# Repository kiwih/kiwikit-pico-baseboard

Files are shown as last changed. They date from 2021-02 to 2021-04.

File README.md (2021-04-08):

# Kiwikit Pico Baseboard

This board provides an easy-to-solder all-throughole 10cm x 10cm 2-layer board which is used in conjunction with a Raspberry Pi Pico for basic, fun experimentation!

render

Features include:
* Three general purpose buttons and a reset button,
* Two general purpose LEDs and a power LED,
* An I2C SSD1306 Screen,
* An I2C AT24 EEPROM
* An LDR for Analog experimentation,
* And a bunch more expansion ports, two of which are arranged to work with cheap SD card and accelerometer modules!

## Usage

The latest schematic in PDF format, and the latest version of the gerbers for manufacture, are located directly 
in the root folder of this repository.

Alternatively, if you want to change any settings / etc, you can download this repository and open it with Kicad.
If so, you'll use this project in tandem with my `kiwih_kicad` Kicad repository: https://github.com/kiwih/kiwih_kicad

## Further documentation

I wrote a blog post to go with this! You can find it [here](https://01001000.xyz/2021-02-13-Raspberry-Pi-Pico-dev-board-Kiwikit/).

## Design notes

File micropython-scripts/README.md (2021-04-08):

## micropython-scripts

In this directory are a number of small micropython scripts you can use to get started with experimenting on the kiwikit-pico-baseboard.

Copy over the at24.py and the ssd1306.py libraries and then you can launch kiwikit.py.

If you're unsure of what to do I recommend perusing the [resources](https://www.raspberrypi.org/documentation/rp2040/getting-started/#getting-started-with-micropython).

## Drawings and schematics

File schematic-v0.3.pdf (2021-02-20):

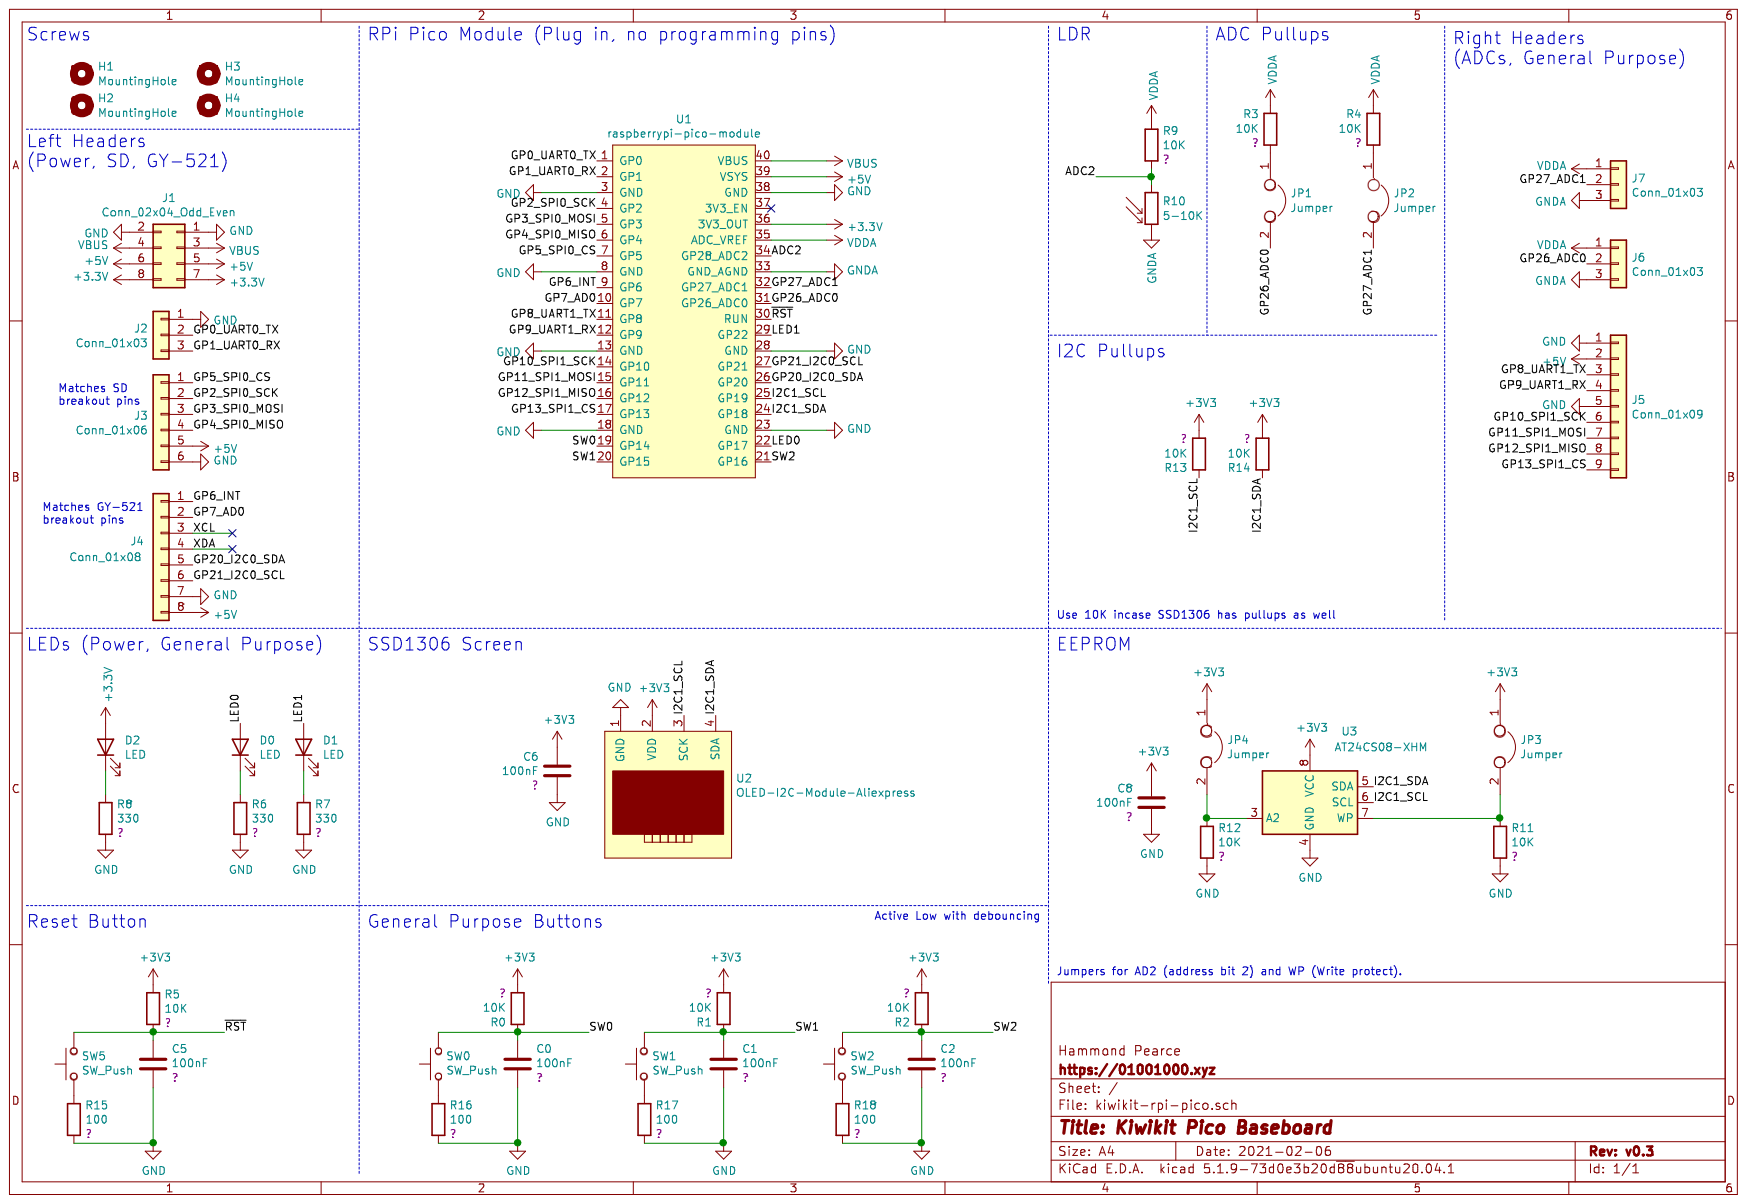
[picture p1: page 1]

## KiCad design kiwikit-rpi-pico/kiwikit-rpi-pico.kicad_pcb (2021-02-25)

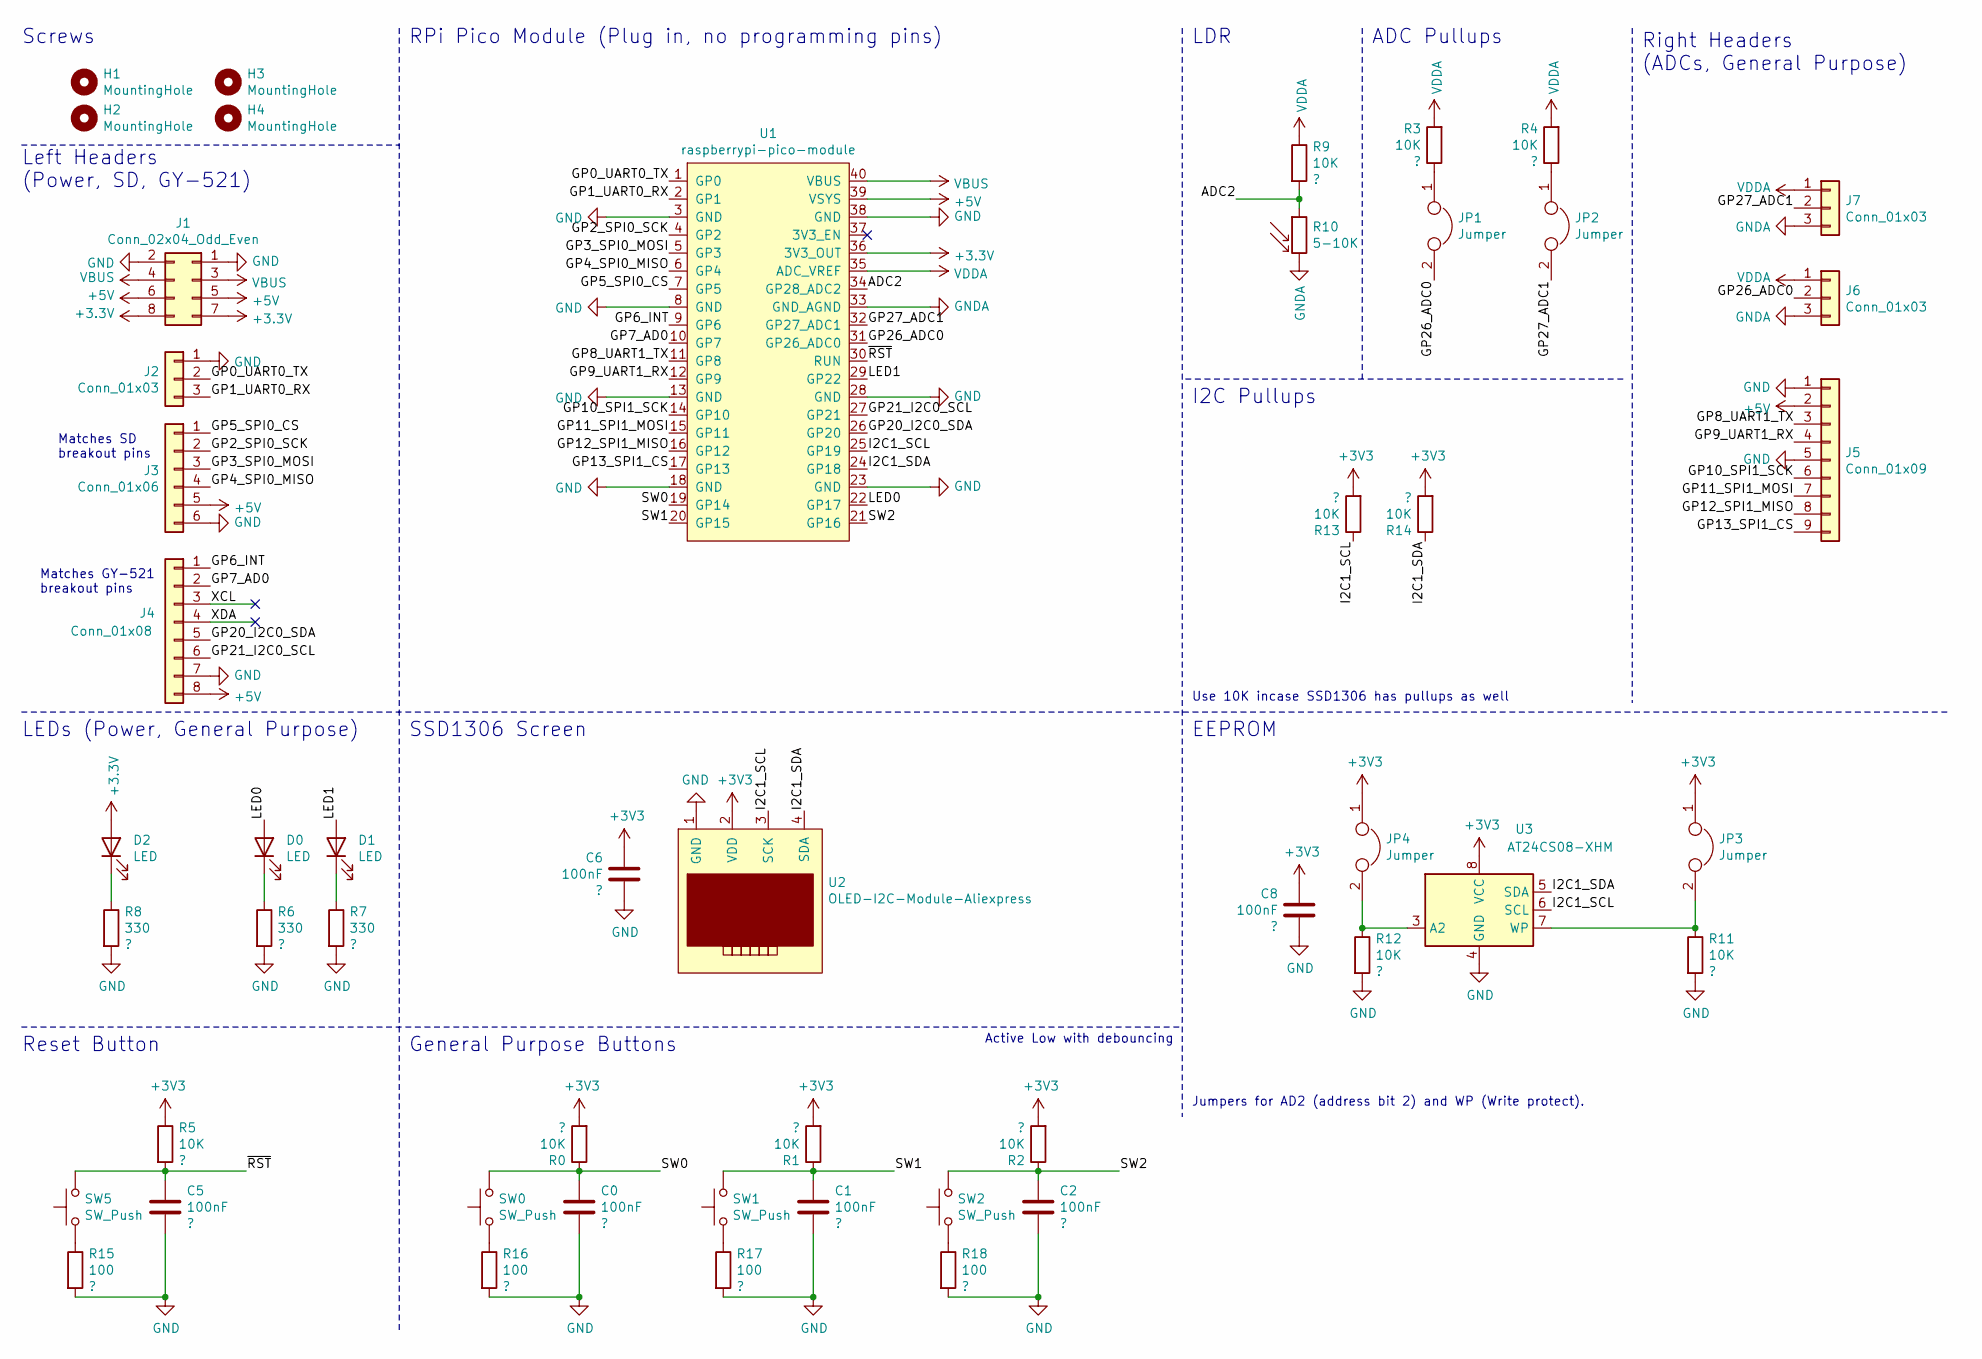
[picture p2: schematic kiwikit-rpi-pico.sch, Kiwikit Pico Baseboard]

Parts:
C0, C1, C2, C5, C6, C8: 100nF; C_Disc_D4.3mm_W1.9mm_P5.00mm
D0, D1, D2: LED; LED_D4.0mm
H1, H2, H3, H4: MountingHole; MountingHole_2.2mm_M2
J1: Conn_02x04_Odd_Even; PinHeader_2x04_P2.54mm_Vertical
J2, J6, J7: Conn_01x03; PinHeader_1x03_P2.54mm_Vertical
J3: Conn_01x06; PinSocket_1x06_P2.54mm_Vertical
J4: Conn_01x08; PinSocket_1x08_P2.54mm_Vertical
J5: Conn_01x09; PinHeader_1x09_P2.54mm_Vertical
JP1, JP2, JP3, JP4: Jumper; PinHeader_1x02_P2.54mm_Vertical
R0, R1, R2, R3, R4, R5, R9, R11, R12, R13, R14: 10K; R_Axial_DIN0207_L6.3mm_D2.5mm_P10.16mm_Horizontal
R6, R7, R8: 330; R_Axial_DIN0207_L6.3mm_D2.5mm_P10.16mm_Horizontal
R10: 5-10K; R_LDR_5.0x4.1mm_P3mm_Vertical
R15, R16, R17, R18: 100; R_Axial_DIN0207_L6.3mm_D2.5mm_P10.16mm_Horizontal
SW0, SW1, SW2: SW_Push; SW_PUSH_6mm_H9.5mm
SW5: SW_Push; SW_PUSH_6mm_H4.3mm
U1: raspberrypi-pico-module
U2: OLED-I2C-Module-Aliexpress
U3: AT24CS08-XHM; DIP-8_W7.62mm

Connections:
+5V: J1.5, J1.6, J3.5, J4.8, J5.2, U1.39 (VSYS)
/ADC2: R9.2, R10.1, U1.34 (GP28_ADC2)
/GP0_UART0_TX: J2.2, U1.1 (GP0)
/GP1_UART0_RX: J2.3, U1.2 (GP1)
/GP2_SPI0_SCK: J3.2, U1.4 (GP2)
/GP3_SPI0_MOSI: J3.3, U1.5 (GP3)
/GP4_SPI0_MISO: J3.4, U1.6 (GP4)
/GP5_SPI0_CS: J3.1, U1.7 (GP5)
/GP6_INT: J4.1, U1.9 (GP6)
/GP7_AD0: J4.2, U1.10 (GP7)
/GP8_UART1_TX: J5.3, U1.11 (GP8)
/GP9_UART1_RX: J5.4, U1.12 (GP9)
/GP10_SPI1_SCK: J5.6, U1.14 (GP10)
/GP11_SPI1_MOSI: J5.7, U1.15 (GP11)
/GP12_SPI1_MISO: J5.8, U1.16 (GP12)
/GP13_SPI1_CS: J5.9, U1.17 (GP13)
/GP20_I2C0_SDA: J4.5, U1.26 (GP20)
/GP21_I2C0_SCL: J4.6, U1.27 (GP21)
/GP26_ADC0: J6.2, JP1.2, U1.31 (GP26_ADC0)
/GP27_ADC1: J7.2, JP2.2, U1.32 (GP27_ADC1)
/I2C1_SCL: R13.1, U1.25 (GP19), U2.3 (SCK), U3.6 (SCL)
/I2C1_SDA: R14.1, U1.24 (GP18), U2.4 (SDA), U3.5 (SDA)
/LED0: D0.2 (A), U1.22 (GP17)
/LED1: D1.2 (A), U1.29 (GP22)
/SW0: C0.2, R0.1, SW0.2, U1.19 (GP14)
/SW1: C1.2, R1.1, SW1.2, U1.20 (GP15)
/SW2: C2.2, R2.1, SW2.2, U1.21 (GP16)
/XCL: J4.3
/XDA: J4.4
/~RST: C5.2, R5.2, SW5.2, U1.30 (RUN)
GND: C0.1, C1.1, C2.1, C5.1, C6.2, C8.2, J1.1, J1.2, J2.1, J3.6, J4.7, J5.1, J5.5, R6.2, R7.2, R8.2, R11.2, R12.2, R15.2, R16.2, R17.2, R18.2, U1.3 (GND), U1.8 (GND), U1.13 (GND), U1.18 (GND), U1.23 (GND), U1.28 (GND), U1.38 (GND), U2.1 (GND), U3.4 (GND)
GNDA: J6.3, J7.3, R10.2, U1.33 (GND_AGND)
unnamed: D0.1 (K), R6.1
unnamed: D1.1 (K), R7.1
unnamed: D2.1 (K), R8.1
unnamed: JP1.1, R3.1
unnamed: JP2.1, R4.1
unnamed: JP3.2, R11.1, U3.7 (WP)
unnamed: JP4.2, R12.1, U3.3 (A2)
unnamed: R15.1, SW5.1
unnamed: R16.1, SW0.1
unnamed: R17.1, SW1.1
unnamed: R18.1, SW2.1
VBUS: J1.3, J1.4, U1.40 (VBUS)
VDDA: J6.1, J7.1, R3.2, R4.2, R9.1, U1.35 (ADC_VREF)

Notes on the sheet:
Matches SD breakout pins
Matches GY-521 breakout pins
I2C Pullups
Right Headers (ADCs, General Purpose)
LDR
EEPROM
SSD1306 Screen
General Purpose Buttons
Reset Button
LEDs (Power, General Purpose)
Left Headers (Power, SD, GY-521)
Screws
RPi Pico Module (Plug in, no programming pins)
ADC Pullups
Use 10K incase SSD1306 has pullups as well
Jumpers for AD2 (address bit 2) and WP (Write protect).
Active Low with debouncing

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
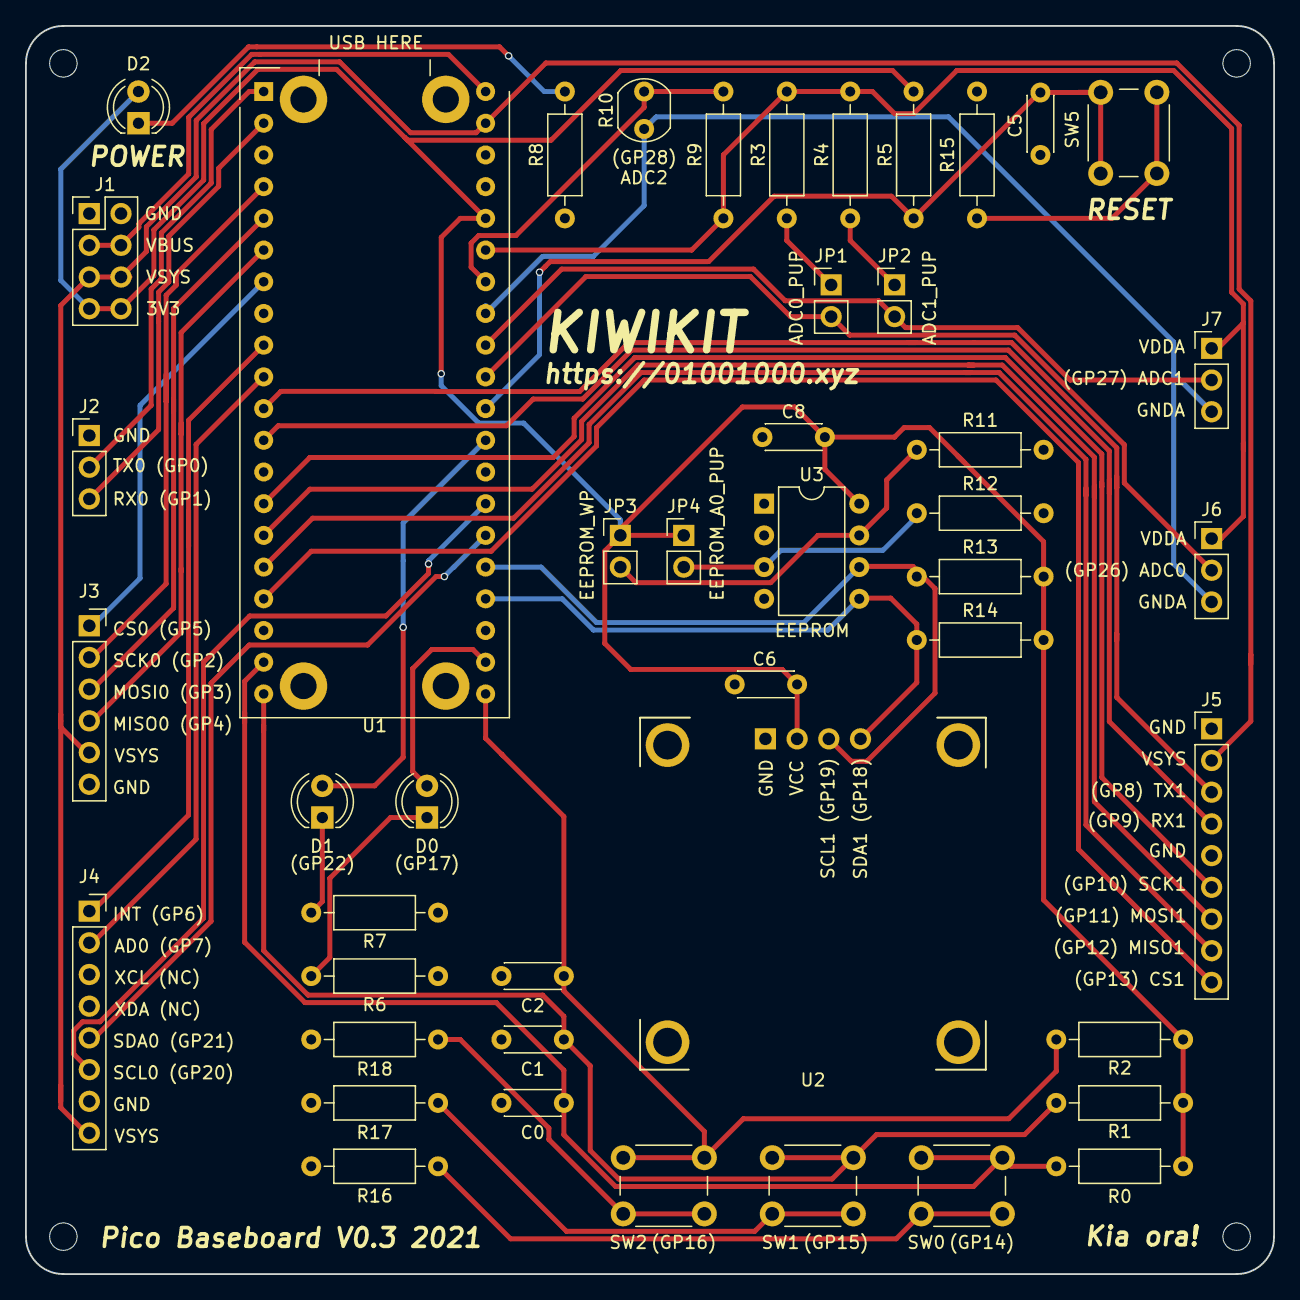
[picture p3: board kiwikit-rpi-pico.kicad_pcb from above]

Board: 2 copper layers, 100.0 x 100.0 mm, 50 parts (0 on the bottom side), 44 nets.

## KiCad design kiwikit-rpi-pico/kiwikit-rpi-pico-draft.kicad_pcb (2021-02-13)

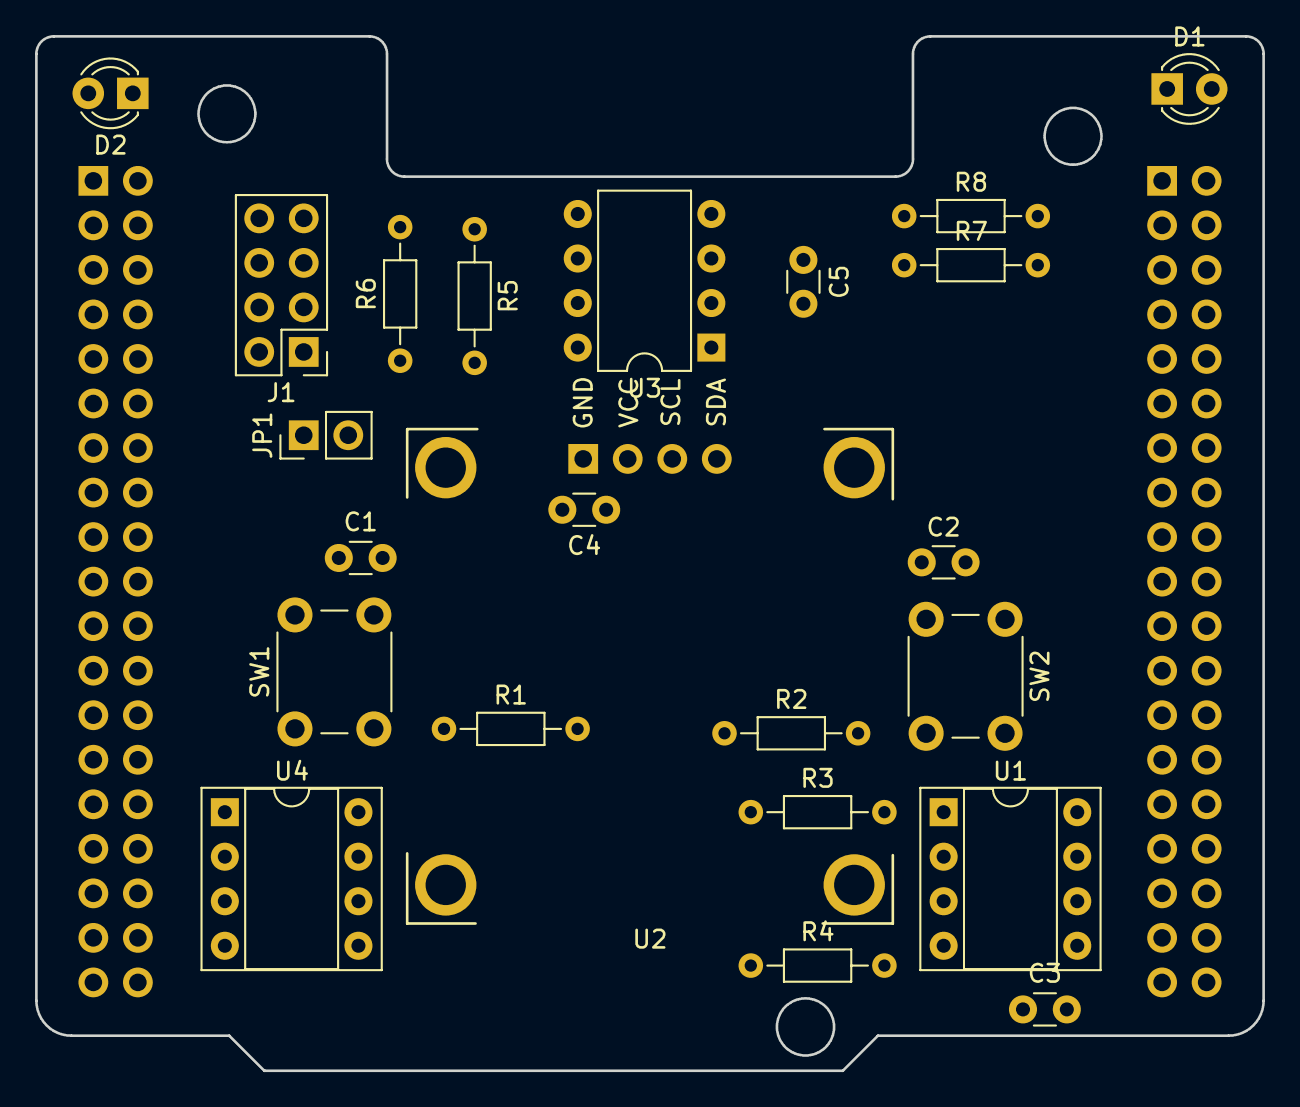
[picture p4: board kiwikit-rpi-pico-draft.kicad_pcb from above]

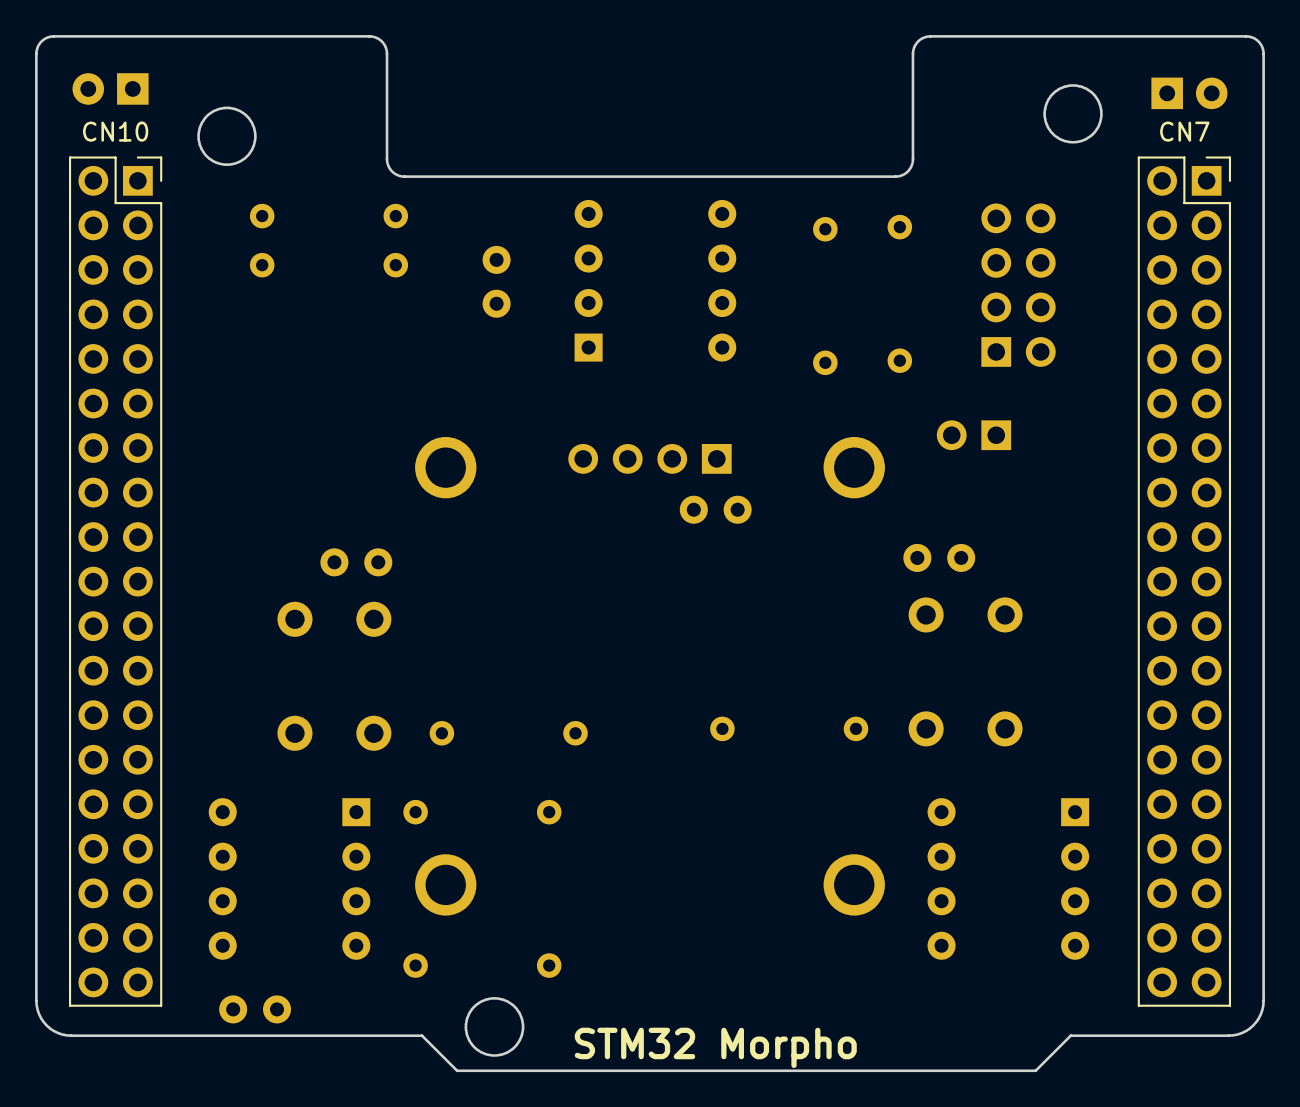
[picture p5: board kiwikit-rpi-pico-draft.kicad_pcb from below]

Board: 2 copper layers, 70.0 x 59.0 mm, 25 parts (2 on the bottom side), 22 nets, no tracks yet.

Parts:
C1, C2, C3, C4, C5: 100nF; C_Disc_D3.0mm_W1.6mm_P2.50mm
CN7, CN10: Conn_02x19_Odd_Even; PinSocket_2x19_P2.54mm_Vertical
D1, D2: LED; LED_D3.0mm
J1: Conn_02x04_Odd_Even; PinHeader_2x04_P2.54mm_Vertical
JP1: Jumper; PinHeader_1x02_P2.54mm_Vertical
R1, R2, R3, R4: 47K; R_Axial_DIN0204_L3.6mm_D1.6mm_P7.62mm_Horizontal
R5: 0; R_Axial_DIN0204_L3.6mm_D1.6mm_P7.62mm_Horizontal
R6: 120; R_Axial_DIN0204_L3.6mm_D1.6mm_P7.62mm_Horizontal
R7, R8: 470; R_Axial_DIN0204_L3.6mm_D1.6mm_P7.62mm_Horizontal
SW1, SW2: SW_Push; SW_PUSH_6mm_H4.3mm
U1: W25Q32JVSS; DIP-8_W7.62mm_Socket
U2: OLED-I2C-Module-Aliexpress
U3: MCP2551-I-P; DIP-8_W7.62mm
U4: AT24CS08-XHM; DIP-8_W7.62mm_Socket

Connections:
+3V3: C3.1, C4.1, C5.1, CN7.16, R1.1, R2.1, R3.1, R4.1, U1.8, U2.2, U4.8
+5V: CN7.18, U3.3
/CAN1_RD: CN10.3, U3.4
/CAN1_TD: CN10.5, U3.1
/CANH: J1.1, J1.2, JP1.1, U3.7
/CANL: J1.3, J1.4, R6.2, U3.6
/I2C1_SCL: CN7.17, U2.3, U4.6
/I2C1_SDA: CN7.15, U2.4, U4.5
/PC5: C2.2, CN10.6, R2.2, SW2.2
/PC6: C1.2, CN10.4, R1.2, SW1.2
/PC8: CN10.2, D1.2
/PC9: CN10.1, D2.2
/SPI3_MISO: CN7.2, U1.2
/SPI3_MOSI: CN7.3, U1.5
/SPI3_SCLK: CN7.1, U1.6
GND: C1.1, C2.1, C3.2, C4.2, C5.2, CN7.8, CN7.19, CN7.20, CN7.22, CN10.9, CN10.20, J1.5, J1.6, R5.2, R7.2, R8.2, SW1.1, SW2.1, U1.4, U2.1, U3.2, U4.4
unnamed: D1.1, R7.1
unnamed: D2.1, R8.1
unnamed: JP1.2, R6.1
unnamed: R3.2, U1.3
unnamed: R4.2, U1.7
unnamed: R5.1, U3.8

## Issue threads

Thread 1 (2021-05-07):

SD card, GY-521 voltage. VSYS and VBUS.

Rudo2204, 2021-05-07:
Thank you for putting up a nicely done breakout board.
I have a question though: shouldn't SD card and GY-521 breakout voltage input pin use the 3.3V line instead of VSYS? These devices often uses 3.3V rather than 5V.
Also naming VSYS as 5V seems strange to me. VSYS can be anything from 1.8V to 5.5V according to the datasheet.
If this board is meant to be used with microUSB cable then using VBUS to get a reliable 5V source seems more reasonable.

kiwih, 2021-05-07:
Thanks for your feedback!
My GY-521 boards have their own voltage regulator onboard to step them down to 3.3V.
The reason VSYS can be lots of different voltages is exactly why we label it VSYS!
As to using VSYS as the voltage bus, the document https://datasheets.raspberrypi.org/pico/pico-datasheet.pdf describes the power chain (section 4.5 and so on). My logic was

1. I want to be able to use the USB port to power the board without a power supply, which neccessitates drawing power out either via VBUS or VSYS,
2. However I also want to protect the upstream USB device - I don't want to accidentally feed voltage backwards into my USB port on my PC if the board is powered externally, so I want the diode to prevent this

This leads towards using VSYS as the voltage bus as it can safely be used to either take power from the USB port to feed the Pico and the dev board, or be used to inject power externally when the USB is unplugged.

Rudo2204, 2021-05-07:
Thank you for your insights to the design. I have checked and it is indeed that both devices can safely be powered with a 5V supply. I have a mfrc522 module that I want to try out with this dev board. It only allows a maximum input voltage of 3.6V so I will be careful when I use that!
I have just one more question to test if I have the correct understanding regarding powering the board externally via VSYS: because we use it as our voltage bus, so in order to both power the pico and the dev board correctly I would have to supply 5V to this pin using the J1 connector on the dev board. It seems like I cannot go lower than 4.5V because of the SD card module requirement or higher than 5.5V because of the pico limit. Is this correct?

kiwih, 2021-05-08:
Those seem like reasonable assumptions to make, yes. It depends on the tolerance of your SD card board as well. I have SD card boards that will go as low as 3.3V. I'm not sure what the upper limit on the Pico is, but certainly the LDO on it will start to get hot if it gets too far beyond 5.5V or so.

Rudo2204, 2021-05-08:
Thanks again for answering all my noob questions. I'm gonna order some boards off JLCPCB and see how it goes!

Closed 2021-05-07.

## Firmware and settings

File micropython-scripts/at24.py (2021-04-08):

from micropython import const

AT24_ROOT_ADDR = const(0xA)

class AT24Exception(Exception):
    pass

class AT24():
    """AT24 class. Manages read/write access to an AT24 EEPROM. 

    Example usage:
    # init i2c
    i2c = I2C(1, scl=Pin(19), sda=Pin(18), freq=100000)

    # init eeprom
    eeprom = AT24(A2_value=1, i2c=i2c)
    
    writebuf = bytearray(2)
    writebuf[0] = 0x01;
    writebuf[1] = 0x02;
    addr = 0x000;
    eeprom.write_bytes(addr, writebuf)
    memory = eeprom.read_bytes(addr, 2)
    print(memory)
    """
    
    def __init__(self, A2_value, i2c):
        """Set up an AT24 class. "A2_value" should be either '1' or '0' and represents the state of the A2 address pin on the AT24 chip. "i2c" is a pre-initialized i2c class."""
        self.A2_value = A2_value
        self.i2c = i2c
        
    def write_bytes(self, address, write_bytearray):
        """Writes up to 16 bytes starting at 10-bit address [address]. All bytes must be on the same page boundary (that is, A[9]-A[4] should be constant). "write_bytearray" is a bytearray."""
        i2c_addr = AT24_ROOT_ADDR << 3 | self.A2_value << 2 | (address & 0x300) >> 8
        mem_addr = address & 0xFF
        
        #The proper way to check if the AT24 chips are ready is to poll the write address and check the NACK.
        #Unfortunately, this isn't possible in the RP2040 port of MicroPython as the low-level I2C functions are not supported
        #Instead, we have to do this using exceptions (an OSError is thrown if the AT24 NACKS)
        #So, this works, but is less efficient than it could be
        attempts = 0
        while attempts < 50: 
            attempts = attempts + 1
            try:
                self.i2c.writeto_mem(i2c_addr, mem_addr, write_bytearray)
                break
            except OSError:
                pass
        
        if attempts >= 50:
            raise AT24Exception("AT24: Write operation timed out (check the address?)")
        
    def read_bytes(self, address, n):
        """Read up to n bytes starting at 10-bit address [address]. Returned as a bytes object."""
        i2c_addr = AT24_ROOT_ADDR << 3 | self.A2_value << 2 | (address & 0x300) >> 8
        mem_addr = address & 0xFF
        #The proper way to check if the AT24 chips are ready is to poll the write address and check the NACK.
        #Unfortunately, this isn't possible in the RP2040 port of MicroPython as the low-level I2C functions are not supported
        #Instead, we have to do this using exceptions (an OSError is thrown if the AT24 NACKS)
        #So, this works, but is less efficient than it could be
        attempts = 0
        while attempts < 50: 
            attempts = attempts + 1
            try:
                data = self.i2c.readfrom_mem(i2c_addr, mem_addr, n)
                break
            except OSError:
                pass
        
        if attempts >= 50:
            raise AT24Exception("AT24: Read operation timed out (check the address?)")
        
        return data

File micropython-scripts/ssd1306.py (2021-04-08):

from micropython import const
import framebuf


# register definitions
SET_CONTRAST = const(0x81)
SET_ENTIRE_ON = const(0xA4)
SET_NORM_INV = const(0xA6)
SET_DISP = const(0xAE)
SET_MEM_ADDR = const(0x20)
SET_COL_ADDR = const(0x21)
SET_PAGE_ADDR = const(0x22)
SET_DISP_START_LINE = const(0x40)
SET_SEG_REMAP = const(0xA0)
SET_MUX_RATIO = const(0xA8)
SET_COM_OUT_DIR = const(0xC0)
SET_DISP_OFFSET = const(0xD3)
SET_COM_PIN_CFG = const(0xDA)
SET_DISP_CLK_DIV = const(0xD5)
SET_PRECHARGE = const(0xD9)
SET_VCOM_DESEL = const(0xDB)
SET_CHARGE_PUMP = const(0x8D)

# Subclassing FrameBuffer provides support for graphics primitives
# http://docs.micropython.org/en/latest/pyboard/library/framebuf.html
class SSD1306(framebuf.FrameBuffer):
    def __init__(self, width, height, external_vcc):
        self.width = width
        self.height = height
        self.external_vcc = external_vcc
        self.pages = self.height // 8
        self.buffer = bytearray(self.pages * self.width)
        super().__init__(self.buffer, self.width, self.height, framebuf.MONO_VLSB)
        self.init_display()

    def init_display(self):
        for cmd in (
            SET_DISP | 0x00,  # off
            # address setting
            SET_MEM_ADDR,
            0x00,  # horizontal
            # resolution and layout
            SET_DISP_START_LINE | 0x00,
            SET_SEG_REMAP | 0x01,  # column addr 127 mapped to SEG0
            SET_MUX_RATIO,
            self.height - 1,
            SET_COM_OUT_DIR | 0x08,  # scan from COM[N] to COM0
            SET_DISP_OFFSET,
            0x00,
            SET_COM_PIN_CFG,
            0x02 if self.width > 2 * self.height else 0x12,
            # timing and driving scheme
            SET_DISP_CLK_DIV,
            0x80,
            SET_PRECHARGE,
            0x22 if self.external_vcc else 0xF1,
            SET_VCOM_DESEL,
            0x30,  # 0.83*Vcc
            # display
            SET_CONTRAST,
            0xFF,  # maximum
            SET_ENTIRE_ON,  # output follows RAM contents
            SET_NORM_INV,  # not inverted
            # charge pump
            SET_CHARGE_PUMP,
            0x10 if self.external_vcc else 0x14,
            SET_DISP | 0x01,
        ):  # on
            self.write_cmd(cmd)
        self.fill(0)
        self.show()

    def poweroff(self):
        self.write_cmd(SET_DISP | 0x00)

    def poweron(self):
        self.write_cmd(SET_DISP | 0x01)

    def contrast(self, contrast):
        self.write_cmd(SET_CONTRAST)
        self.write_cmd(contrast)

    def invert(self, invert):
        self.write_cmd(SET_NORM_INV | (invert & 1))

    def show(self):
        x0 = 0
        x1 = self.width - 1
        if self.width == 64:
            # displays with width of 64 pixels are shifted by 32
            x0 += 32
            x1 += 32
        self.write_cmd(SET_COL_ADDR)
        self.write_cmd(x0)
        self.write_cmd(x1)
        self.write_cmd(SET_PAGE_ADDR)
        self.write_cmd(0)
        self.write_cmd(self.pages - 1)
        self.write_data(self.buffer)


class SSD1306_I2C(SSD1306):
    def __init__(self, width, height, i2c, addr=0x3C, external_vcc=False):
        self.i2c = i2c
        self.addr = addr
        self.temp = bytearray(2)
        self.write_list = [b"\x40", None]  # Co=0, D/C#=1
        super().__init__(width, height, external_vcc)

    def write_cmd(self, cmd):
        self.temp[0] = 0x80  # Co=1, D/C#=0
        self.temp[1] = cmd
        self.i2c.writeto(self.addr, self.temp)

    def write_data(self, buf):
        self.write_list[1] = buf
        self.i2c.writevto(self.addr, self.write_list)


class SSD1306_SPI(SSD1306):
    def __init__(self, width, height, spi, dc, res, cs, external_vcc=False):
        self.rate = 10 * 1024 * 1024
        dc.init(dc.OUT, value=0)
        res.init(res.OUT, value=0)
        cs.init(cs.OUT, value=1)
        self.spi = spi
        self.dc = dc
        self.res = res
        self.cs = cs
        import time

        self.res(1)
        time.sleep_ms(1)
        self.res(0)
        time.sleep_ms(10)
        self.res(1)
        super().__init__(width, height, external_vcc)

    def write_cmd(self, cmd):
        self.spi.init(baudrate=self.rate, polarity=0, phase=0)
        self.cs(1)
        self.dc(0)
        self.cs(0)
        self.spi.write(bytearray([cmd]))
        self.cs(1)

    def write_data(self, buf):
        self.spi.init(baudrate=self.rate, polarity=0, phase=0)
        self.cs(1)
        self.dc(1)
        self.cs(0)
        self.spi.write(buf)
        self.cs(1)

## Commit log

2021-02-13 First commit V0.2 - First public commit
    [kiwikit-rpi-pico-draft.kicad_pcb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]
2021-02-20 Update to version 0.3, adjust debouncer layout.
    [kiwikit-rpi-pico.kicad_pcb, kiwikit-rpi-pico.sch]
2021-02-20 Add v0.3 schematic pdf
2021-02-25 Generate v0.3 gerbers
    [kiwikit-rpi-pico-B_Cu.gbr, kiwikit-rpi-pico-B_SilkS.gbr, kiwikit-rpi-pico-Edge_Cuts.gbr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]
2021-03-02 Update to fix missing gerber file
